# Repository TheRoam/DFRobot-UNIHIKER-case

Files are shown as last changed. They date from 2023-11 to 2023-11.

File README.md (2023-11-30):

# DFRobot-UNIHIKER-case
Open-source DFRobot themed cases for UNIHIKER dev board

DFR_case-strip

case_v1

1. Access the **model viewer** via:
https://theroam.github.io/DFRobot-UNIHIKER-case/

2. Download existing models in **blender**  folder.
   Check the .md file of each model for details.
   
4. **Contribute** with editions or new models by doing a **pull request**.

Any new cases or improvements to the viewer are much appreciated!

**Thanks!**

**[THE ROAMING WORKSHOP](https://theroamingworkshop.cloud)**

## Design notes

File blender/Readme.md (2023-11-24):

When uploading new models, please include:
- .md Readme file to explain model features
- .blend Blender file
- .stl exported ready-to-print file

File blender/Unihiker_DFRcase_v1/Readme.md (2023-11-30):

Blender file containing 3D case design for DFRobot UNIHIKER

Version 1.0.1

Themed to look like DFRobot logo.

-Case features:
1. Top openings for text display through screen.
2. Side opening for USB-C connection.
3. Foot-like support for vertical standing.
4. Back opening for external sensor cabling.
5. Back extrusions for 40mm speaker placement.

-Case structure:
1. Bottom piece acts as a casing.
2. Support piece holds UNIHIKER board to the case using the inbuilt screws
3. Top piece acts as a cover and clips on bottom piece.

-Assembly instructions:

[https://theroamingworkshop.cloud/b/en/2498/](https://theroamingworkshop.cloud/b/en/2498/)

Changelog:
v1.0.1
- Fixes feet extrusion misadjustment

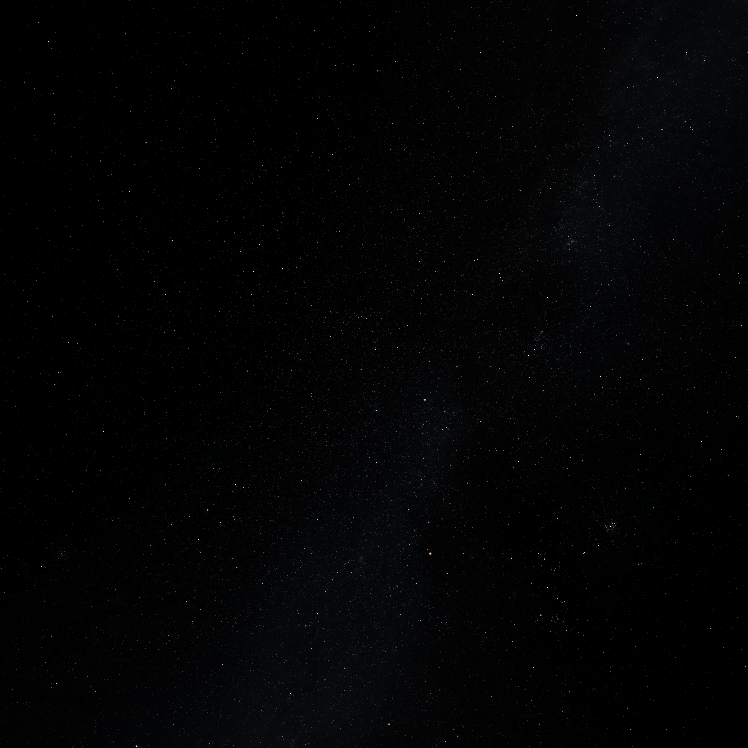
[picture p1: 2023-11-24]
skybox-sb1-north.png

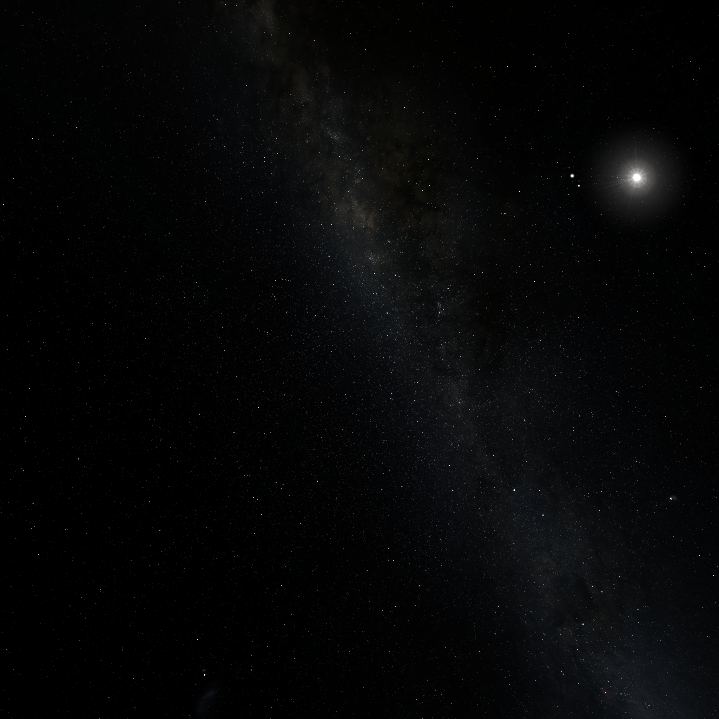
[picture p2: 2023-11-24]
skybox-sb3-south.png

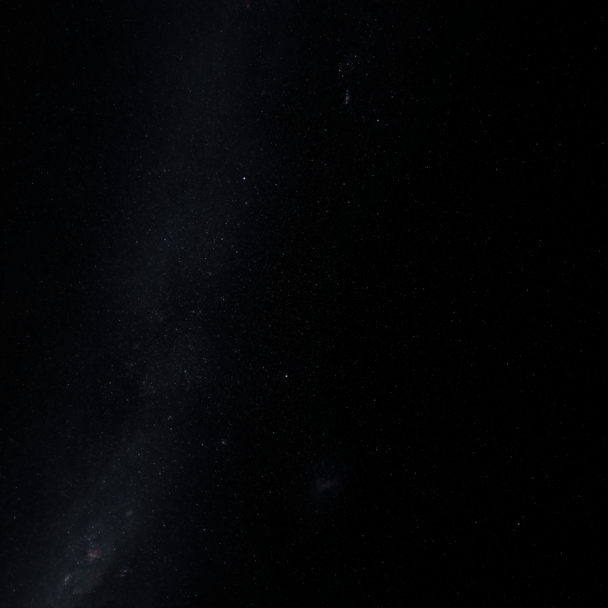
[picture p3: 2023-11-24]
skybox-sb6-bottom+90.png

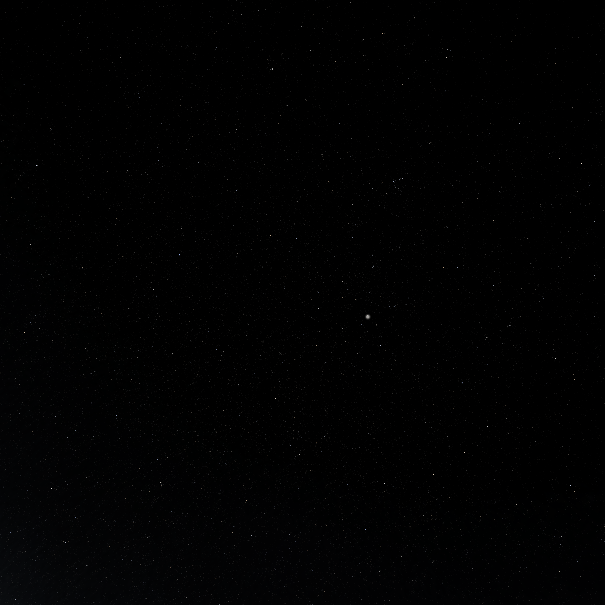
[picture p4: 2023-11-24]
skybox-sb4-west.png

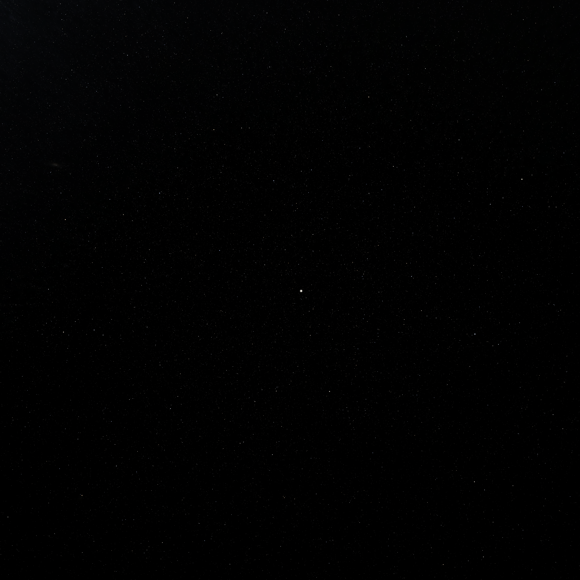
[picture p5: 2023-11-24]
skybox-sb2-east.png

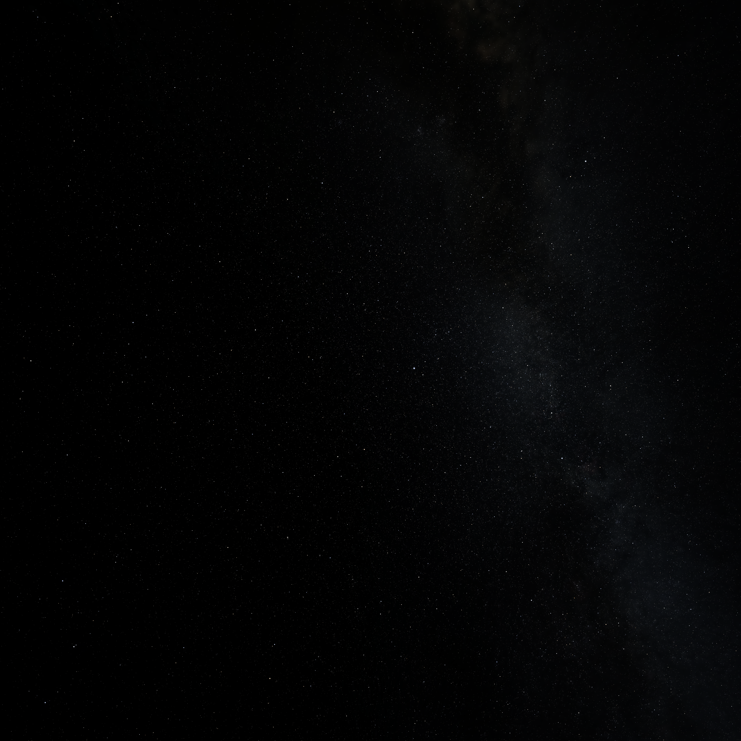
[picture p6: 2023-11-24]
skybox-sb5-top-90.png

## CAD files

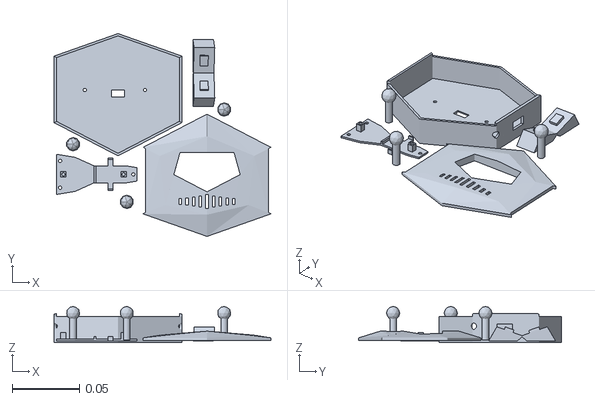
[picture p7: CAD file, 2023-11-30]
blender/Unihiker_DFRcase_v1/Unihiker_DFRcase_v1-0-1.stl
0.162 x 0.151 x 0.0269

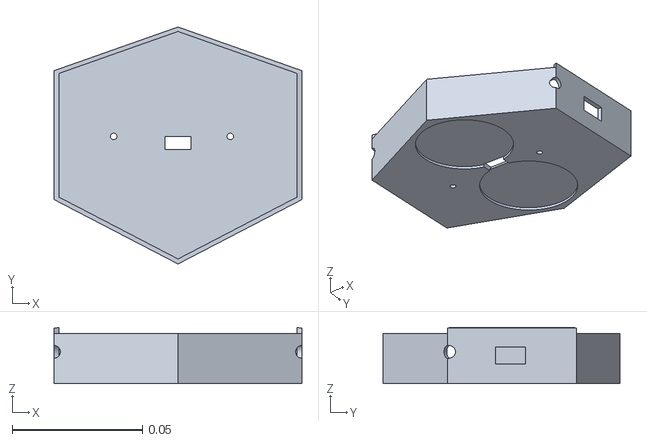
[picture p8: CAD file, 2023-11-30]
blender/Unihiker_DFRcase_v1/DFR_base.stl
0.0953 x 0.091 x 0.0216

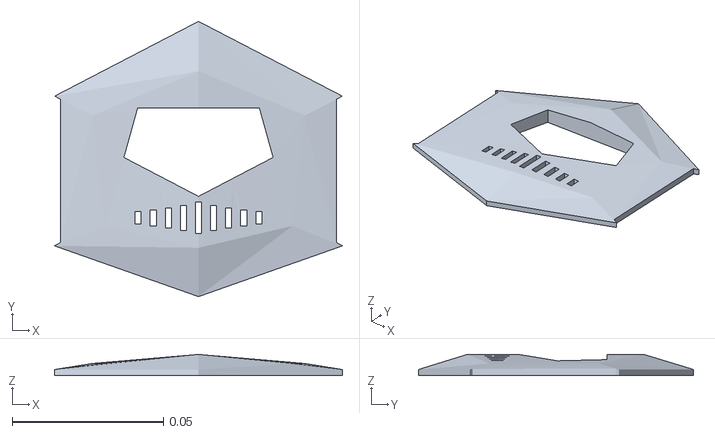
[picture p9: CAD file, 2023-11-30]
blender/Unihiker_DFRcase_v1/DFR_top.stl
0.0953 x 0.091 x 0.007

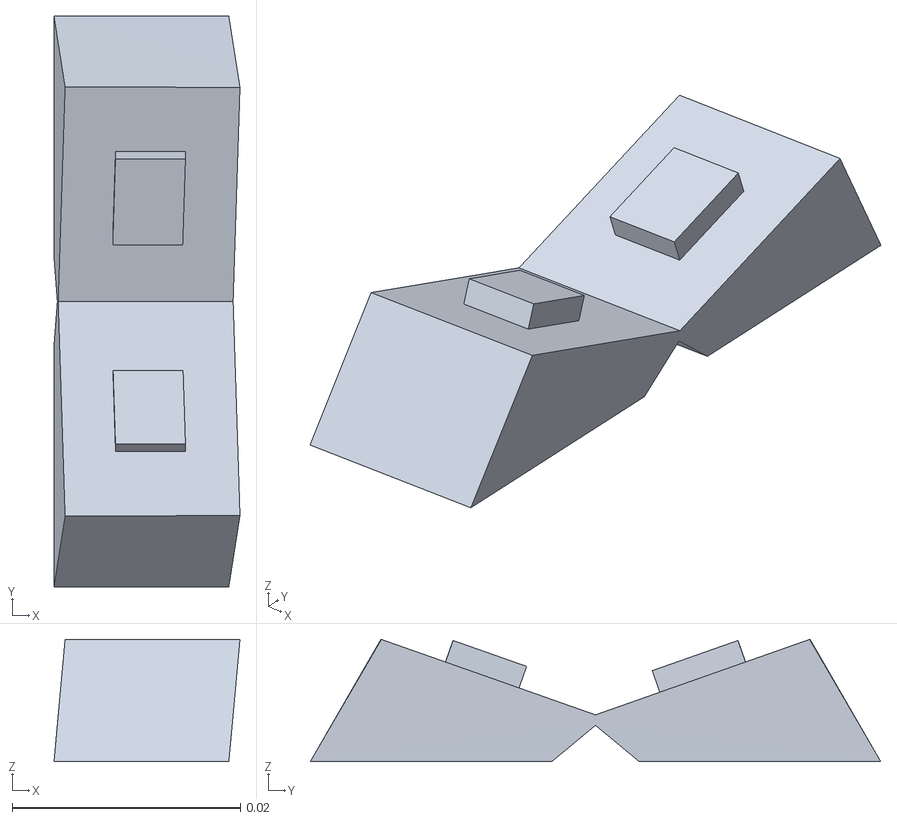
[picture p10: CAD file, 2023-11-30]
blender/Unihiker_DFRcase_v1/DFR_feet.stl
0.0163 x 0.05 x 0.0107

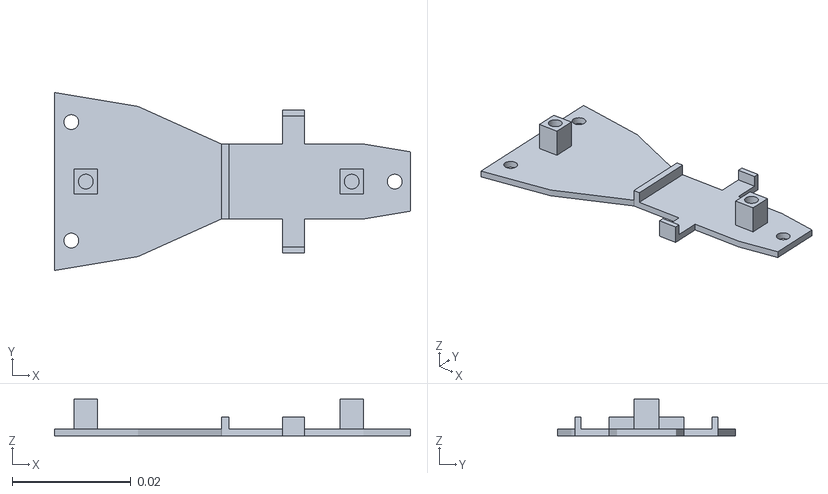
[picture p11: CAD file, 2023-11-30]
blender/Unihiker_DFRcase_v1/DFR_holder.stl
0.06 x 0.03 x 0.0062

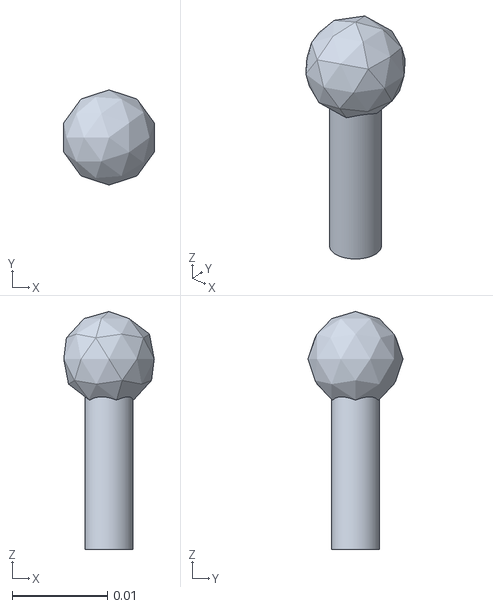
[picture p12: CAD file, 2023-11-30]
blender/Unihiker_DFRcase_v1/DFR_antena.stl
0.00951 x 0.01 x 0.025

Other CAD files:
blender/Unihiker_DFRcase_v1/Unihiker_DFRcase_v1.stl

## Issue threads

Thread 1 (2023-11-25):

v1 misadjustments

TheRoam, 2023-11-25:
1. **Antennas** need sanding in order to fit the holes and later glueing so they dont move
2. **Feet support** needs cutting one of the extrusions as they dont fit in the voids directly
3. **Base** needs to be deeper to give more room to the speakers (they are usually 5mm deep and the extrusion in only 1mm)
4. **Top cover** has some weird tiangulation in the right hand side. It is weird because it was designed with mirroring properties...

TheRoam, 2023-11-30:
Feet support is fixed in latest individual .stl and Blender files

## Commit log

2023-11-30 moved to individual folder
    [Unihiker_DFRcase_v1.blend]
2023-11-30 uplodaded individual files
    [DFR_antena.stl, DFR_base.stl, DFR_feet.stl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]
2023-11-30 updated case pictures
2023-11-30 added assembly instructions
